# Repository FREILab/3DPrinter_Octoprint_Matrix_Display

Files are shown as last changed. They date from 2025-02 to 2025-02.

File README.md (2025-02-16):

# Matrix Display for reminaing print time (Octoprint)

This is a hardware / software project to display the remianing print time for the FREILab printers

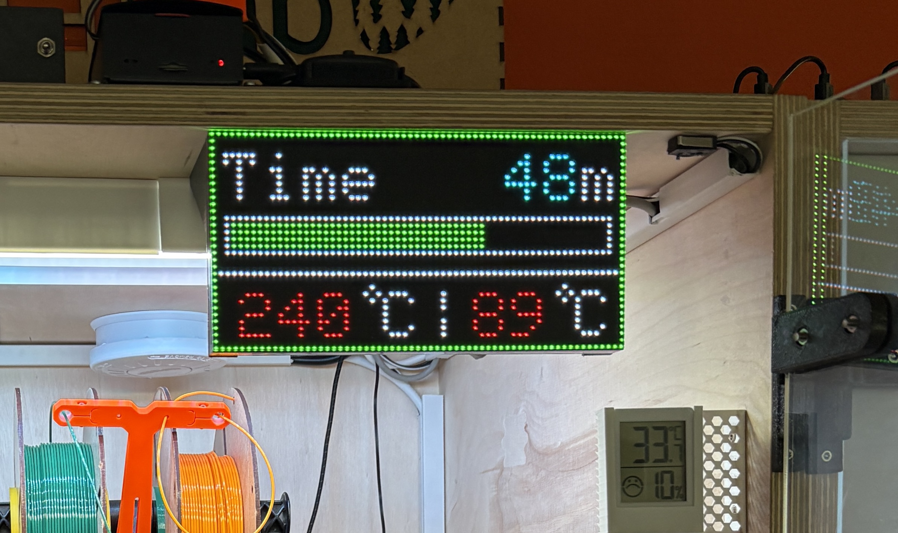
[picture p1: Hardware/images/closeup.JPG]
Closup of display Closeup


## Overview
The Display is powered by to the Raspberry Pi which controls the 3D Printer via Octoprint. The Adafruit MCU Board MatrixPortal S3 connects via its built in WiFi card to the Octoprint Instance and displays the current hotend and bed temperature as well as the print job progress and remaining time on the matrix display.

## Hardware
The following hardware is used:
- MCU Board: Adafruit MatrixPortal S3: https://www.adafruit.com/product/5778
- LED Matrix: 64x32 RGB LED Matrix - 3mm pitch (IC: usually HUB75); different vendors available, e.g.: https://www.adafruit.com/product/2279
- Power Supply: a USB-C interface capable of 5V, 1.5A is sufficient, for example a raspberry pi USB output port. In normal mode I measured at 5V about 0.15A draw for the display and MCU.
- Wire it according to the adafruit design guide: https://learn.adafruit.com/32x16-32x32-rgb-led-matrix/overview
- A 3D printed overhead mount was used to mount the Display and the MCU board.
- The Display is fixed with 5 M3x12/M3x16 screws
- For the board four M2 heat inserts and four M2 screws are required

## Software
The display uses these significant libraries:
- Adafruit Protomatter (Display driver): https://github.com/adafruit/Adafruit_Protomatter
- OctoPrintAPI to fetch the print progress: https://github.com/chunkysteveo/OctoPrintAPI
- enter the WiFi credentials and Octorint IP, Port and API key in the file "secret.h"

The were some issues with the Octoprint API which locked up the MCU when a print job was started/finished. Instead of fixing the API itself, a simple watchdog was implemented to restart the Adafruit MatrixPortal S3 when the software freezes.

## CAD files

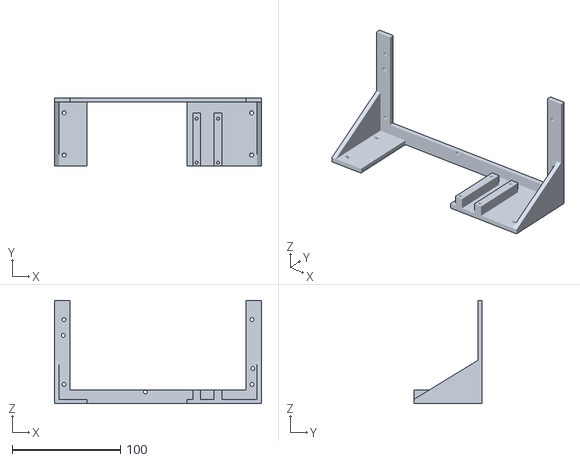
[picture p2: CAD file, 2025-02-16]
Hardware/mount/Display_Mount.stl
191.2 x 63.0 x 95.5

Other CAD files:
Hardware/mount/Display_Mount.f3d

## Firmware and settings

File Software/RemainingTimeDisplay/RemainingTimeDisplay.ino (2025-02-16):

/**********************************************************************
 *  A sketch to display to read out the state of a Octoprint          *
 *  instance and display it onto a matrix LED display.                *
 *                                                                    *
 *  Necessary acces data has to be provided to the secret.h           *
 *  02/2025                                                           *
 *  By Marius Tetard for FREILab Freiburg e.V. https://freilab.de     *
 *                                                                    *
 *  This software is open source and licensed under the MIT License.  *
 *  See the LICENSE file or visit https://opensource.org/licenses/MIT *
 *  for more details.                                                 *
**********************************************************************/


#include <WiFi.h>
#include <WiFiClient.h>
#include "secret.h"
#include <OctoPrintAPI.h>          // For connection to OctoPrint
#include <Adafruit_Protomatter.h>  // For RGB matrix
#include <esp_task_wdt.h>          // For watchdog timer


#define HEIGHT 32   // Matrix height (pixels) - SET TO 64 FOR 64x64 MATRIX!
#define WIDTH 64    // Matrix width (pixels)
#define MAX_FPS 45  // Maximum redraw rate, frames/second

uint8_t rgbPins[] = { 42, 41, 40, 38, 39, 37 };
uint8_t addrPins[] = { 45, 36, 48, 35, 21 };
uint8_t clockPin = 2;
uint8_t latchPin = 47;
uint8_t oePin = 14;

#if HEIGHT == 16
#define NUM_ADDR_PINS 3
#elif HEIGHT == 32
#define NUM_ADDR_PINS 4
#elif HEIGHT == 64
#define NUM_ADDR_PINS 5
#endif

Adafruit_Protomatter matrix(
  WIDTH, 4, 1, rgbPins, NUM_ADDR_PINS, addrPins,
  clockPin, latchPin, oePin, true);

int16_t textX;  // Current text position (X)
int16_t textY;  // Current text position (Y)
char str[64];   // Buffer to text

// Constants for Wi-Fi reconnection
const unsigned long CHECK_INTERVAL = 1000;  // Check Wi-Fi every 1 second
unsigned long previousMillis = 0;

// Setup Octoprint
WiFiClient client;
const char* ip_address = CONFIG_IP;
IPAddress ip(ip_address);
const int octoprint_httpPort = CONFIG_PORT;
String octoprint_apikey = SECRET_API;  //See top of file or GIT Readme about getting API key
// Initialize OctoPrint API
OctoprintApi api(client, ip, octoprint_httpPort, octoprint_apikey);


const int tempGood_T0 = 50; // below this temperature T0 is considered cool
const int tempGood_T1 = 50; // below this temperature T1 is considered cool

// Watchdog timeout (3 seconds)
/* info on core mask:
  .idle_core_mask = (1 << portNUM_PROCESSORS) - 1
  ESP32 has two cores -> 0001
  shift two times to the left -> 0100
  subtract one -> 0011
*/
esp_task_wdt_config_t twdt_config
{
  timeout_ms:     2000U,
  idle_core_mask: 0b011,
  trigger_panic:  true
};

void setup() {
  // Start Serial Interface
  Serial.begin(115200);
  delay(500);

  // Start LED Matrix
  ProtomatterStatus status = matrix.begin();
  Serial.print("[Matrix] Protomatter begin() status: ");
  Serial.println((int)status);

  // Wifi not yet connected
  displayWiFiOffline();

  // connect to WiFi
  connectToWiFi();

  // Initialize the watchdog timer
  esp_task_wdt_init(&twdt_config); // Enable panic reset
  esp_task_wdt_add(NULL); // Add current task to watchdog
}

void loop() {
  unsigned long currentMillis = millis();

  // Check the Wi-Fi connection every second
  if (currentMillis - previousMillis >= CHECK_INTERVAL) {
    previousMillis = currentMillis;

    if (WiFi.status() != WL_CONNECTED) {
      displayWiFiOffline();
      Serial.println("[WiFi] Wi-Fi lost. Reconnecting...");
      reconnectWiFi();
    } else {
      Serial.println("[WiFi] Wi-Fi active");

      // printOctoprintDebug();

      // Check on Octoprint
      if (api.getPrinterStatistics()) {
        Serial.println("[OctoPrint] Octoprint active");

        // State: printer ready (operational + ready)
        if (api.printerStats.printerStateoperational && api.printerStats.printerStateready) {
          // Printer is ready
          displayPrinterReady(api.printerStats.printerTool0TempActual, api.printerStats.printerBedTempActual);
        }
        // State printer printing (operational + printing)
        if (api.printerStats.printerStateoperational && api.printerStats.printerStatePrinting) {
          // Printer is printing
          // get job status
          api.getPrintJob();
          float progress = (float)api.printJob.progressPrintTime / ((float)api.printJob.progressPrintTime + (float)api.printJob.progressPrintTimeLeft);

          displayPrinterPrinting(
            api.printJob.progressPrintTimeLeft,
            progress,
            api.printerStats.printerTool0TempActual,
            api.printerStats.printerBedTempActual);
        }

      } else {
        Serial.println("[OctoPrint] Octoprint offline");
        displayWiFiOffline();
      }
    }
  }
  // Feed the watchdog to prevent a reset
  esp_task_wdt_reset();
}

void connectToWiFi() {
  Serial.println("[WiFi] Connecting to Wi-Fi...");
  WiFi.begin(SECRET_SSID, SECRET_PASS);

  int attempts = 0;
  Serial.print("[WiFi] ");
  while (WiFi.status() != WL_CONNECTED && attempts < 10) {
    delay(500);
    Serial.print(".");
    attempts++;
  }

  if (WiFi.status() == WL_CONNECTED) {
    Serial.println("\nConnected to Wi-Fi.");
    Serial.println("[WiFi] IP Address: " + WiFi.localIP().toString());
  } else {
    Serial.println("\nFailed to connect to Wi-Fi.");
  }
}

void reconnectWiFi() {
  WiFi.disconnect();
  WiFi.reconnect();

  int attempts = 0;
  Serial.print("[WiFi] ");
  while (WiFi.status() != WL_CONNECTED && attempts < 10) {
    delay(500);
    Serial.print(".");
    attempts++;
  }

  if (WiFi.status() == WL_CONNECTED) {
    Serial.println("\nReconnected to Wi-Fi.");
  } else {
    Serial.println("\nReconnection attempt failed.");
  }
}


void displayPrinterPrinting(int seconds, float progress, int temp_T0, int temp_T1) {
  int h = seconds / 3600;
  int min = (seconds % 3600) / 60;

  // necessary variables
  int h_ones, h_tens, m_tens, m_ones;

  // Extract digits
  h_tens = h / 10;  // Extract tens place
  h_ones = h % 10;  // Extract ones place

  m_tens = min / 10;  // Extract tens place
  m_ones = min % 10;  // Extract ones place

  // cap tens places
  if (h_tens > 9) { h_tens = 9; }
  if (m_tens > 6) { m_tens = 5; }

  // Fill background black
  matrix.fillScreen(0);
  matrix.setTextWrap(false);
  matrix.setTextSize(1);
  // draw border
  matrix.drawRect(0, 0, 64, 32, matrix.color565(0, 255, 0));  // green

  // Text "Time" (always)
  sprintf(str, "Time");
  textX = 2;
  textY = 3;
  matrix.setTextColor(0xFFFF);  // white
  matrix.setCursor(textX, textY);
  matrix.println(str);

  // Minutes Text (always)
  sprintf(str, "m");
  textX = 57;
  textY = 3;
  matrix.setTextColor(0xFFFF);  // white
  matrix.setCursor(textX, textY);
  matrix.println(str);

  // Minutes ones (always)
  textX = 51;
  textY = 3;
  matrix.setTextColor(matrix.color565(0, 255, 255));  // bright blue
  matrix.setCursor(textX, textY);
  matrix.println(m_ones);

  // Minutes tens (if h>0 or m_tens>0)
  if ((h > 0) or (m_tens > 0)) {
    textX = 45;
    textY = 3;
    matrix.setTextColor(matrix.color565(0, 255, 255));  // bright blue
    matrix.setCursor(textX, textY);
    matrix.println(m_tens);
  }

  // Hours Text (if h>0)
  if (h > 0) {
    sprintf(str, "h");
    textX = 38;
    textY = 3;
    matrix.setTextColor(0xFFFF);  // white
    matrix.setCursor(textX, textY);
    matrix.println(str);
  }

  // Hours ones (if h>0)
  if (h > 0) {
    textX = 32;
    textY = 3;
    matrix.setTextColor(matrix.color565(0, 255, 255));  // bright blue
    matrix.setCursor(textX, textY);
    matrix.println(h_ones);
  }

  // Hours tens (if h>9)
  if (h > 9) {
    textX = 26;
    textY = 3;
    matrix.setTextColor(matrix.color565(0, 255, 255));  // bright blue
    matrix.setCursor(textX, textY);
    matrix.println(h_tens);
  }

  // Draw Progressbar outline
  matrix.drawRect(2, 12, 60, 6, matrix.color565(128, 128, 128));  // gray

  // draw the progress bar length depending on the progress
  int bar_max_progress = scaleFloatToInteger(progress);
  for (int i = 3; i < bar_max_progress; i = i + 1) {
    matrix.drawRect(i, 13, 1, 4, matrix.color565(0, 255, 0));  // green
  }

  // blink the last bar if necesary

  int blink = 0;
  if ((millis() / 1000) % 2) {
    blink = 0;
  } else {
    blink = 1;
  }

  if (blink == 1) {
    if (bar_max_progress == 3) { bar_max_progress = 4; }
    matrix.drawRect(bar_max_progress - 1, 13, 1, 4, matrix.color565(0, 0, 0));  // black
  }

  // Line separating Progress and Temperatures
  matrix.drawRect(1, 20, 62, 1, matrix.color565(255, 255, 255));  // white

  // Display T0
  if(temp_T0 < 10) {
    textX = 16;
  } else if (temp_T0 < 100) {
    textX = 10;
  } else if (temp_T0 >= 100) {
    textX = 4;
  }
  textY = 23;
  if (temp_T0 >= tempGood_T0) {
    // hot
    matrix.setTextColor(matrix.color565(255, 0, 0));  // red
  } else {
    // cool
    matrix.setTextColor(matrix.color565(0, 255, 0));  // green
  }
  matrix.setCursor(textX, textY);
  matrix.println(temp_T0);

  // display "C" of "°C"
  textX = 26;
  textY = 23;
  matrix.setTextColor(matrix.color565(255, 255, 255));  // white
  matrix.setCursor(textX, textY);
  matrix.println("C");

  // display "°" of "°C"
  matrix.drawCircle(textX-2, textY, 1, matrix.color565(255, 255, 255)); // white

  // Display Slash
  textX = 33;
  textY = 23;
  matrix.setTextColor(matrix.color565(255, 255, 255));  // white
  matrix.setCursor(textX, textY);
  matrix.println("|");

  // Display T1
  if(temp_T1 < 10) {
    textX = 46;
  } else if (temp_T1 >= 10) {
    textX = 40;
  }
  textY = 23;
  if (temp_T1 >= tempGood_T1) {
    // hot
    matrix.setTextColor(matrix.color565(255, 0, 0));  // red
  } else {
    // cool
    matrix.setTextColor(matrix.color565(0, 255, 0));  // green
  }
  matrix.setCursor(textX, textY);
  matrix.println(temp_T1);

  // display "C" of "°C"
  textX = 56;
  textY = 23;
  matrix.setTextColor(matrix.color565(255, 255, 255));  // white
  matrix.setCursor(textX, textY);
  matrix.println("C");

  // display "°" of "°C"
  matrix.drawCircle(textX-2, textY, 1, matrix.color565(255, 255, 255)); // white

  // Update Display
  matrix.show();
}

void displayPrinterReady(int temp_T0, int temp_T1) {

  // Fill background black
  matrix.fillScreen(0);
  matrix.setTextWrap(false);
  matrix.setTextSize(1);

  // draw border
  matrix.drawRect(0, 0, 64, 32, matrix.color565(255, 255, 0));  // yellow

  // Text "Ready" (always)
  sprintf(str, "Ready");
  textX = 2;
  textY = 3;
  matrix.setTextColor(0xFFFF);  // white
  matrix.setCursor(textX, textY);
  matrix.println(str);

  // Draw Progressbar outline
  matrix.drawRect(2, 12, 60, 6, matrix.color565(128, 128, 128));  // gray

  // Line separating Progress and Temperatures
  matrix.drawRect(1, 20, 62, 1, matrix.color565(255, 255, 255));  // white

  // Display T0
  if(temp_T0 < 10) {
    textX = 16;
  } else if (temp_T0 < 100) {
    textX = 10;
  } else if (temp_T0 >= 100) {
    textX = 4;
  }
  textY = 23;
  if (temp_T0 >= tempGood_T0) {
    // hot
    matrix.setTextColor(matrix.color565(255, 0, 0));  // red
  } else {
    // cool
    matrix.setTextColor(matrix.color565(0, 255, 0));  // green
  }
  matrix.setCursor(textX, textY);
  matrix.println(temp_T0);

  // display "C" of "°C"
  textX = 26;
  textY = 23;
  matrix.setTextColor(matrix.color565(255, 255, 255));  // white
  matrix.setCursor(textX, textY);
  matrix.println("C");

  // display "°" of "°C"
  matrix.drawCircle(textX-2, textY, 1, matrix.color565(255, 255, 255)); // white

  // Display Slash
  textX = 33;
  textY = 23;
  matrix.setTextColor(matrix.color565(255, 255, 255));  // white
  matrix.setCursor(textX, textY);
  matrix.println("|");

  // Display T1
  if(temp_T1 < 10) {
    textX = 46;
  } else if (temp_T1 >= 10) {
    textX = 40;
  }
  textY = 23;
  if (temp_T1 >= tempGood_T1) {
    // hot
    matrix.setTextColor(matrix.color565(255, 0, 0));  // red
  } else {
    // cool
    matrix.setTextColor(matrix.color565(0, 255, 0));  // green
  }
  matrix.setCursor(textX, textY);
  matrix.println(temp_T1);

  // display "C" of "°C"
  textX = 56;
  textY = 23;
  matrix.setTextColor(matrix.color565(255, 255, 255));  // white
  matrix.setCursor(textX, textY);
  matrix.println("C");

  // display "°" of "°C"
  matrix.drawCircle(textX-2, textY, 1, matrix.color565(255, 255, 255)); // white

  // Update Display
  matrix.show();
}

void displayOctoprintOffline() {
  // Fill background black
  matrix.fillScreen(0);
  matrix.setTextWrap(false);
  matrix.setTextSize(1);
  // draw border
  matrix.drawRect(0, 0, 64, 32, matrix.color565(255, 0, 0));  // red

  // Text time (always)
  sprintf(str, "Octoprint");
  textX = 2;
  textY = 3;
  matrix.setTextColor(0xFFFF);  // white
  matrix.setCursor(textX, textY);
  matrix.println(str);

  sprintf(str, "offline");
  textX = 2;
  textY = 14;
  matrix.setTextColor(0xFFFF);  // white
  matrix.setCursor(textX, textY);
  matrix.println(str);

  // Update Display
  matrix.show();
}

void displayWiFiOffline() {
  // Fill background black
  matrix.fillScreen(0);
  matrix.setTextWrap(false);
  matrix.setTextSize(1);
  // draw border
  matrix.drawRect(0, 0, 64, 32, matrix.color565(255, 0, 0));  // red

  // Text time (always)
  sprintf(str, "WiFi");
  textX = 2;
  textY = 3;
  matrix.setTextColor(0xFFFF);  // white
  matrix.setCursor(textX, textY);
  matrix.println(str);

  sprintf(str, "offline");
  textX = 2;
  textY = 14;
  matrix.setTextColor(0xFFFF);  // white
  matrix.setCursor(textX, textY);
  matrix.println(str);

  // Update Display
  matrix.show();
}

// Scale a float between 0 to 1 to a int between 3 and 61
int scaleFloatToInteger(float value) {
  // Ensure the input value stays within the expected range
  value = constrain(value, 0.0, 1.0);

  // Map the float to the integer range [3, 61]
  int scaledValue = round(value * (61 - 3) + 3);

  return scaledValue;
}

// debug: print octoprint API data
void printOctoprintDebug() {
  if (api.getPrinterStatistics()) {
    Serial.println();
    Serial.println("---------States---------");
    Serial.print("Printer Current State: ");
    Serial.println(api.printerStats.printerState);
    Serial.print("Printer State - closedOrError:  ");
    Serial.println(api.printerStats.printerStateclosedOrError);
    Serial.print("Printer State - error:  ");
    Serial.println(api.printerStats.printerStateerror);
    Serial.print("Printer State - operational:  ");
    Serial.println(api.printerStats.printerStateoperational);
    Serial.print("Printer State - paused:  ");
    Serial.println(api.printerStats.printerStatepaused);
    Serial.print("Printer State - printing:  ");
    Serial.println(api.printerStats.printerStatePrinting);
    Serial.print("Printer State - ready:  ");
    Serial.println(api.printerStats.printerStateready);
    Serial.print("Printer State - sdReady:  ");
    Serial.println(api.printerStats.printerStatesdReady);
    Serial.println("------------------------");
    Serial.println();
    Serial.println("------Termperatures-----");
    Serial.print("Printer Temp - Tool0 (°C):  ");
    Serial.println(api.printerStats.printerTool0TempActual);
    Serial.print("Printer State - Tool1 (°C):  ");
    Serial.println(api.printerStats.printerTool1TempActual);
    Serial.print("Printer State - Bed (°C):  ");
    Serial.println(api.printerStats.printerBedTempActual);
    Serial.println("------------------------");
  }
}

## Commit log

2025-01-26 display wifi connection with led
2025-01-26 Added port, added print job progress
2025-02-02 start temperature display
2025-02-02 finished printing layout
2025-02-02 implemented temperature display; pade therefore finished
2025-02-02 add display functions; simple printer connection is working
2025-02-06 working; only progress and time remaining missing
    [RemainingTimeDisplay.ino]
2025-02-09 add color coding for temperature
2025-02-09 fixed double call issue
    [RemainingTimeDisplay.ino]
2025-02-09 add watchdog timer
2025-02-16 Add 3D-model
    [Display_Mount.f3d, Display_Mount.stl]
